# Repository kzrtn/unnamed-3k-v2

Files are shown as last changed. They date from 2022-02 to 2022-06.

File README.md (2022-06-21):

# unnamed-3k-v2 keypad
 A simple 3 key mechanical hotswap keypad for osu! Uses an Atmega32u2 (also compatible with Atmega16u2). Created using Kicad and AutoCad/Coreldraw.
 
 keypad image
 another keypad image
 
 ## IMPORTANT
 This uploaded version of the keypad is **slightly changed** from the prototype in the pictures above.
 
 **Changes:**
 - Removed in-key LEDs
 - Changed north facing switches to south facing
 - Switch pins were changed from B4, B6, B7 to B7, C7, C6
 - Removed unnecessary vias.

This means that what is put up here is **untested**. However if you've tried producing this and everything checks out (it should, changes were very minor) please send me an email at `jolene.tkk@gmail.com` or contact me somehow. I'll update this page and/or fix any issues raised.
 
 ## Features
 - Cherry MX hotswap
 - Uses QMK and has VIA (sort of)
 - 1000hz, chordsplits at 1ms
 - Acrylic sandwich
 - RGB underglow

**Notes regarding QMK and VIA:**

This is not pushed into QMK or VIA's repo. QMK source files are found in the firmware folder. To use VIA with the keypad, go to `settings tab in the VIA software > enable 'Show Design Tab > go to Design tab > Load Draft Definition > Upload the 'load_in_VIA.json' file from qmk-unnamed3kv2-source folder`. **You will have to do this each time you want to use VIA**.

## Settings and RGB modes
Upon plugging in, you will be booted into **Layer 0** where it outputs Z, X and C (play mode). To change RGB modes, hold down the first button (first button on the far left) while plugging in the keypad. It will boot into **Layer 1**.
### Layer 0
| First key  | Second key | Third key |
| --- | --- |--- |
| Z | X  | C |
### Layer 1
| First key  | Second key | Third key |
| --- | --- |--- |
| Change RGB Mode | Toggle RGB on/off | Go to Layer 2 |
### Layer 2
| First key  | Second key | Third key |
| --- | --- |--- |
| Hue value + | Hue value - | Go to Layer 3 |
### Layer 3
| First key  | Second key | Third key |
| --- | --- |--- |
| Sat value + | Sat value - | Go to Layer 4 |
### Layer 4
| First key  | Second key | Third key |
| --- | --- |--- |
| Brightness value + | Brightness value - | Go to Layer 0 |

**RGB MODES**

- Breathing
- Rainbow mood
- Rainbow swirl
- Static

## Required parts
- PCB with components
- Laser cut acrylic
- 4 x M2 17mm hex stands
- 8 x M2 screws
- (optional) Rubber feet

## PCB assembly tips
3D view PCB
PCB in Kicad

The BOM and POS files in `PCB files/Gerber and JLCPCB files` are generated for easy ordering from [JLCPCB](https://jlcpcb.com/). For any parts that are unavailable, especially the crystal and/or the capacitors for the crystal, choose something else that's also 16Mhz with another capacitive load value that's available. Calculate the new values for the caps of the new crystal accordingly using this formula:
```
CL = ((CX1 x CX2) / (CX1 + CX2)) + Cstray

CL: The crystal load capacitance
CX1: The first capacitor
CX2: The second capacitor
Cstray: The stray capacitance in the oscillator circuit, which will normally be in the 2pF to 5pF range.

Assuming that CX1=CX2 then the equation becomes:

CL = ((CX1 x CX1) / (2 x CX1)) + Cstray

CL = (CX1 / 2) + Cstray

Rearranging the equation, we can find the external load capacitor value:

CX1 = 2(CL - Cstray)

For example, if the crystal load capacitance is 15pF, and assuming Cstray=2pF, then:

CX1 = CX2 = 2(15pF - 2pF) = 26pF
```

In the event that you would like to use an **atmega16u2** instead of atmega32u2, you can just do that, no PCB edits is required. But please read the firmware notes section of this readme to adjust the firmware accordingly.

| Part name  | Package type | Notes |
| --- | --- |--- |
| Crystal  | SMD3225-4P  | 16MHz is REQUIRED |
| Capacitors  | 0805  |  |
| Resistors | 0805 | |
| Fuse | 1206 | [This](https://lcsc.com/product-detail/Resettable-Fuses_TECHFUSE-nSMD025-24V_C70069.html) is the one I used. Otherwise, ensure your fuse is rated 500mA |
| Kailh hotswap sockets |  | [They're](https://lcsc.com/product-detail/Mechanical-Keyboard-Shaft_Kailh-CPG151101S11_C2803348.html) now available on JLCPCB and LCSC |
| WS2812B (LEDs) |  | Easily found on [JLCPCB](https://lcsc.com/product-detail/Light-Emitting-Diodes-LED_Worldsemi-WS2812B-B-W_C2761795.html) and other websites |
| Tactile switch |  | Easily found on [JLCPCB](https://lcsc.com/product-detail/Tactile-Switches_ALPSALPINE-SKQGABE010_C115351.html) and other websites |

## Acrylic case notes
Case thickness

There are 3 different file formats here. AutoCAD, Coreldraw and PDF.

AutoCAD files are in the 'might be broken and wrong thickness' folder. When I tried exporting the AutoCAD files to .pdf, it would export in the wrong size. I'm not sure if the drawings themselves in the AutoCad files are wrong. They are also outdated, layers are not labelled with the correct thickness, if you use the AutoCAD files, please check the dimensions and the correct the thickness labels to the image shown above (image edited from `new laser cut 16.0.pdf`. The other issue with the AutoCAD file is that the USB cut out size is too big, it will not cover the underside of the USB port properly, if you plan to use AutoCAD, please edit this accordingly.

Coreldraw files are available in latest and 16.0 versions. I'm not sure if both of them are properly up to date (my Coreldraw trial has expired). Please check if they meet the requirements I pointed out in the paragraph above. I'd stick with the `new laser cut 16.0.pdf` file, because that's the last file I used.

**Additional note:** The holes for the hex stands can be quite tight in the `new laser cut 16.0.pdf` file. If they're too tight for your hex stands, enlarge them a little.

For best light diffusion effects, the last layer should use a matte/frosted piece of acrylic. The top of layer can also be matte/frosted for good light diffusion on the top.

## Firmware notes
To flash the firmware, use [QMK toolbox](https://github.com/qmk/qmk_toolbox). Load one of the `.hex` files provided in the `firmware/qmk hex files` folder. `unnamed3kv2_default.hex` does not have (manual) VIA support. `unnamed3kv2_via.hex` has (manual) VIA support. Make sure that the MCU is set to `atmega32u2`, if you are using `atmega16u2`, change it to that instead.

QMK toolbox

For tinkering with the firmware source, all the files are in `firmware/unnamed3kv2source`. To compile, use QMK MSYS.

**In the case where you are using an atmega16u2**, you'll have to edit the `rules.mk` file in `firmware/unnamed3kv2source`. Change `MCU = atmega32u2` to `MCU = atmega16u2` and recompile the firmware with [QMK MSYS](https://msys.qmk.fm/).

## Printing your own images for decoration
Reuse the same `new laser cut 16.0.pdf` file. Load it into an image editor like Photoshop and put it over whatever image you'd like to use and export it as an image or .pdf then print it out on a piece of paper. **Remember to check fill image to paper size** or similar setting your printer has. Make sure there is no margins so the printed image is the correct size.

**[Print settings example](https://cdn.discordapp.com/attachments/733003518465540278/988617787540930600/print_sizing.png)**

## Learning PCB design with this project
This makes a decent reference, but I don't advise using the same libraries as me because they're outdated and trigger clearance errors in Kicad. Please use [ebalster's keyboard parts library](https://github.com/ebastler/marbastlib) for parts instead.

**Useful resources**
- [My PCB design notes](https://docs.google.com/document/d/1xsjb1sf3pxFw8bXC4gNhWsFhWNOthMoyz6RiJc1UtVI/edit)
- [Best PCB design practices](https://gist.github.com/Sleepdealr/ab05f5edb82eae9e0393f4d63da55adf)

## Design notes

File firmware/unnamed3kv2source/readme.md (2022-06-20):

# unnamed-3k-v2

unnamed-3k-v2

*A short description of the keyboard/project*

* Keyboard Maintainer: [kzrtn](https://github.com/yourusername)
* Hardware Supported: *The PCBs, controllers supported*
* Hardware Availability: *Links to where you can find this hardware*

Make example for this keyboard (after setting up your build environment):

    make unnamed-3k-v2:default

Flashing example for this keyboard:

    make unnamed-3k-v2:default:flash

See the [build environment setup](https://docs.qmk.fm/#/getting_started_build_tools) and the [make instructions](https://docs.qmk.fm/#/getting_started_make_guide) for more information. Brand new to QMK? Start with our [Complete Newbs Guide](https://docs.qmk.fm/#/newbs).

## Bootloader

Enter the bootloader in 3 ways:

* **Bootmagic reset**: Hold down the key at (0,0) in the matrix (usually the top left key or Escape) and plug in the keyboard
* **Physical reset button**: Briefly press the button on the back of the PCB - some may have pads you must short instead
* **Keycode in layout**: Press the key mapped to `RESET` if it is available

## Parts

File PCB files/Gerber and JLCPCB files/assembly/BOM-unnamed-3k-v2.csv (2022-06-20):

Comment | Designator | Footprint | LCSC
MX-NoLED | MX2 | MXOnly-1U-Hotswap
MX-NoLED | MX3 | MXOnly-1U-Hotswap
MX-NoLED | MX1 | MXOnly-1U-Hotswap
1uF | C1 | C_0805_2012Metric_Pad1.15x1.40mm_HandSolder
10uF | C6 | C_0805_2012Metric_Pad1.15x1.40mm_HandSolder
0.1uF | C11 | C_0805_2012Metric_Pad1.15x1.40mm_HandSolder
10k | R3 | R_0805_2012Metric_Pad1.15x1.40mm_HandSolder
10k | R4 | R_0805_2012Metric_Pad1.15x1.40mm_HandSolder
5.1k | R5 | R_0805_2012Metric_Pad1.15x1.40mm_HandSolder
5.1k | R6 | R_0805_2012Metric_Pad1.15x1.40mm_HandSolder
PRTR5V0U2X | U2 | SOT143B
HRO-TYPE-C-31-M-12 | USB1 | HRO-TYPE-C-31-M-12-HandSoldering
ATmega32U2-AU | U1 | TQFP-32_7x7mm_P0.8mm
Polyfuse_Small | F1 | Fuse_1206_3216Metric_Pad1.42x1.75mm_HandSolder
SW_Push | SW1 | SKQGADE010
0.1uF | C5 | C_0805_2012Metric_Pad1.15x1.40mm_HandSolder
WS2812B | D5 | LED_WS2812B_PLCC4_5.0x5.0mm_P3.2mm
0.1uF | C10 | C_0805_2012Metric_Pad1.15x1.40mm_HandSolder
WS2812B | D4 | LED_WS2812B_PLCC4_5.0x5.0mm_P3.2mm
Crystal_GND24_Small | Y1 | Crystal_SMD_3225-4Pin_3.2x2.5mm_HandSoldering
14pF | C3 | C_0805_2012Metric_Pad1.15x1.40mm_HandSolder
14pF | C2 | C_0805_2012Metric_Pad1.15x1.40mm_HandSolder
0.1uF | C4 | C_0805_2012Metric_Pad1.15x1.40mm_HandSolder
22 | R2 | R_0805_2012Metric_Pad1.15x1.40mm_HandSolder
22 | R1 | R_0805_2012Metric_Pad1.15x1.40mm_HandSolder

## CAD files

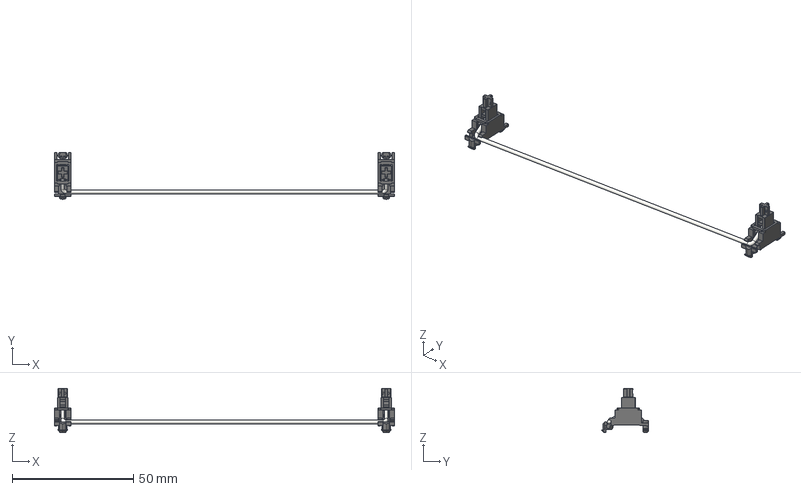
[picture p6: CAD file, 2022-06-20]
PCB files/keyswitch-kicad-library/source_3d/Mounting_Keyboard_Stabilizer/Stabilizer_Cherry_MX_8u.FCStd
140.1 x 19.2 x 18.3 mm
Bar
Stabilizer_Key_
Stabilizer_Base_
Stabilizer_Key
Stabilizer_Base

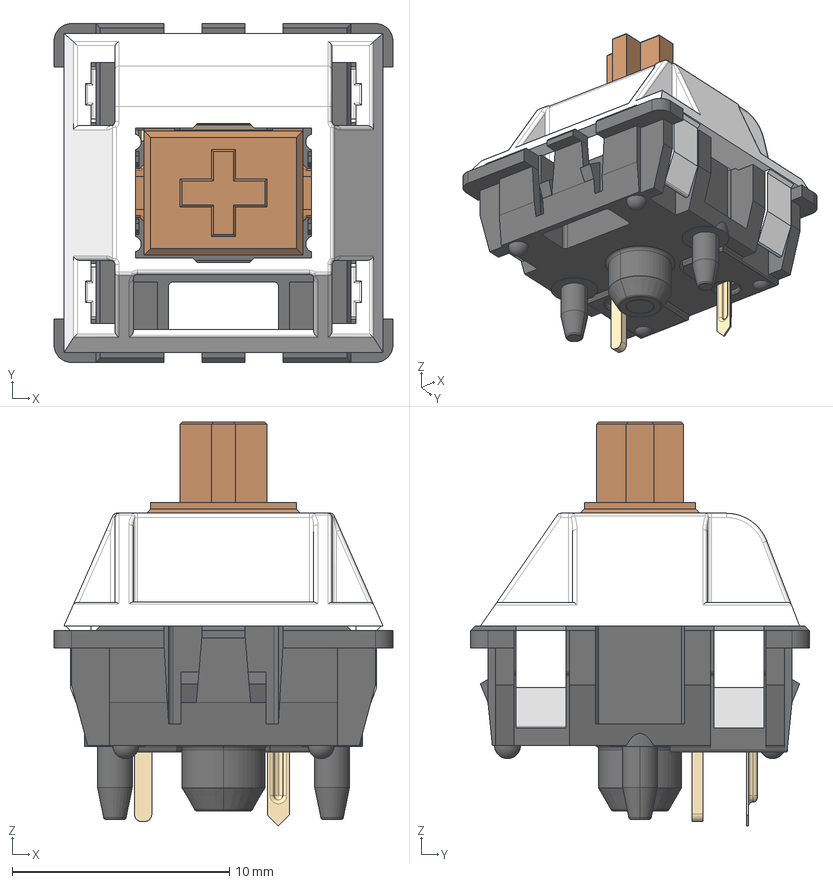
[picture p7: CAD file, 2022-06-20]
PCB files/keyswitch-kicad-library/source_3d/Switch_Keyboard_Cherry_MX/SW_Cherry_MX_PCB.FCStd
15.6 x 15.6 x 18.6 mm
Lower_Housing
Upper_Housing
Stem
Pin_1
Pin_2
Spring
Clicker

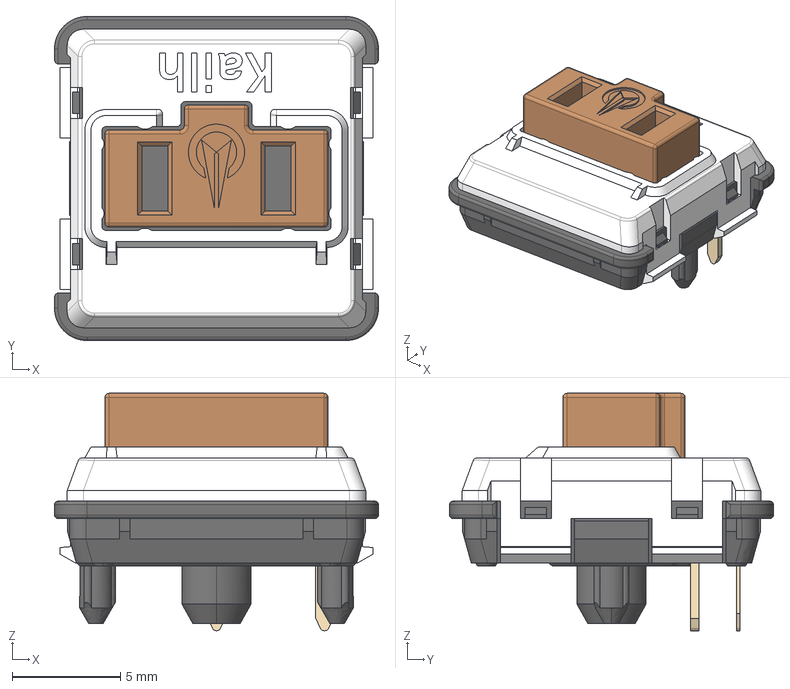
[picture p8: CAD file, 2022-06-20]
PCB files/keyswitch-kicad-library/source_3d/Switch_Keyboard_Kailh/SW_Kailh_Choc_V1.FCStd
15.0 x 15.0 x 11.0 mm
Upper_Housing
Lower_Housing
Stem
Pin_2
Pin_1

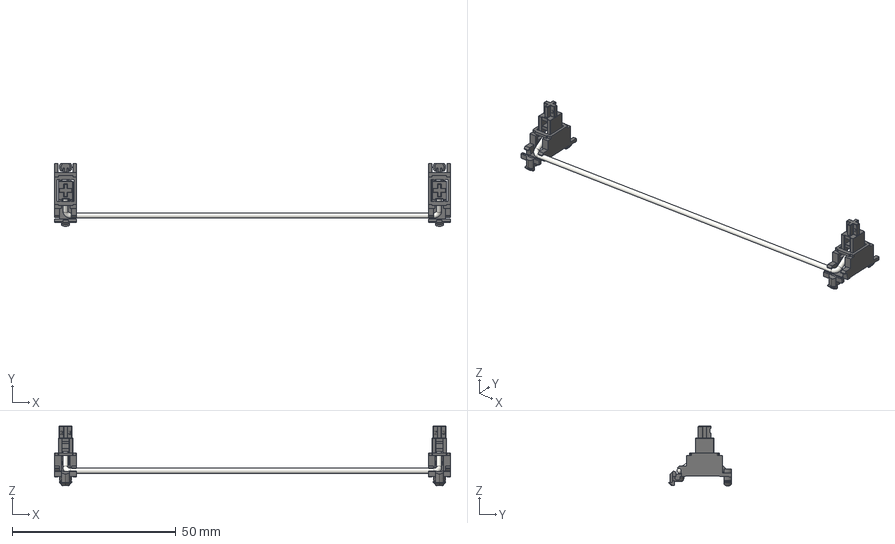
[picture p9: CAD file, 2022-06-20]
PCB files/keyswitch-kicad-library/source_3d/Mounting_Keyboard_Stabilizer/Stabilizer_Cherry_MX_7u.FCStd
121.1 x 19.2 x 18.3 mm
Bar
Stabilizer_Key_
Stabilizer_Base_
Stabilizer_Key
Stabilizer_Base

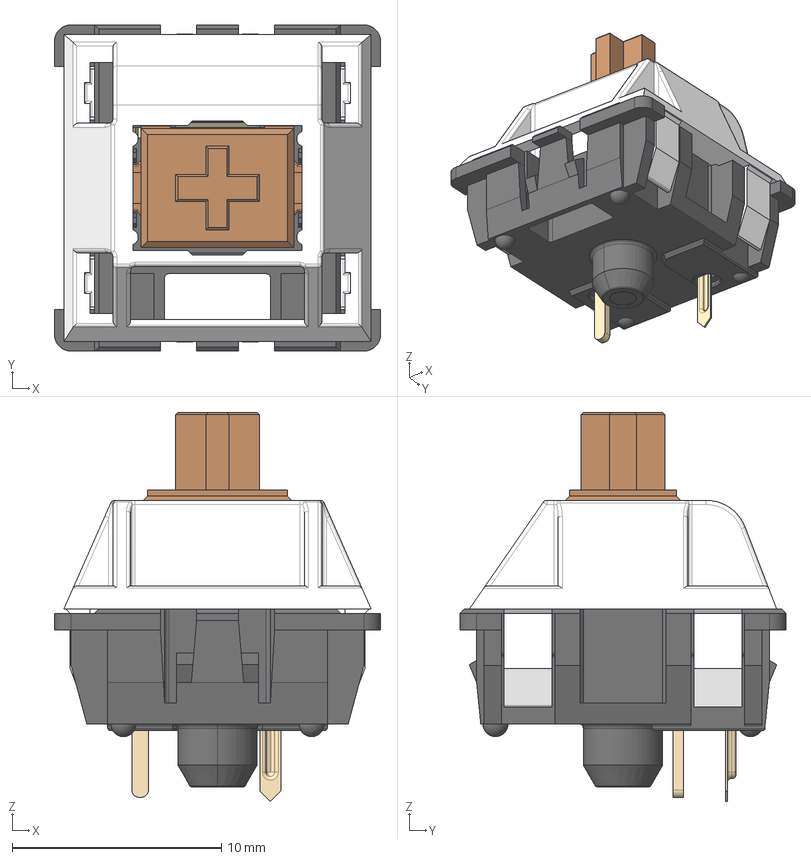
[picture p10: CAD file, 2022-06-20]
PCB files/keyswitch-kicad-library/source_3d/Switch_Keyboard_Cherry_MX/SW_Cherry_MX_Plate.FCStd
15.6 x 15.6 x 18.6 mm
Lower_Housing
Upper_Housing
Stem
Pin_1
Pin_2
Spring
Clicker

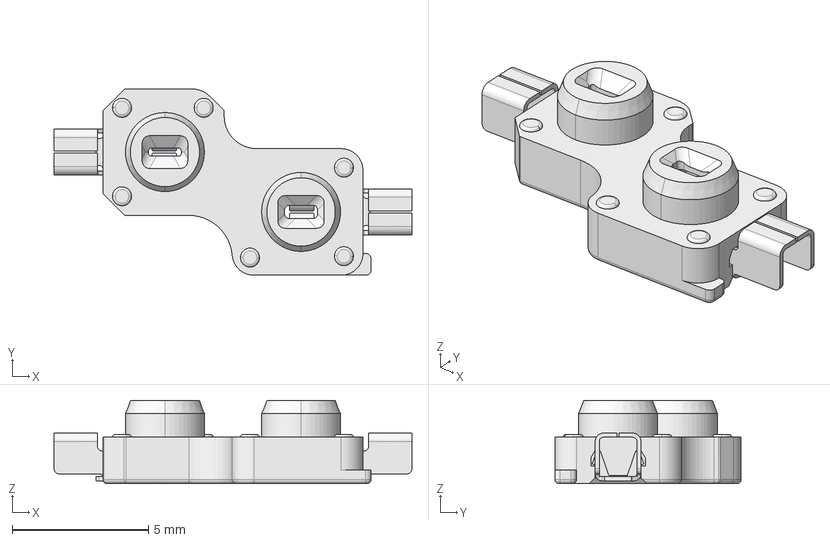
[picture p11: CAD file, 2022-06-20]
PCB files/keyswitch-kicad-library/source_3d/Switch_Keyboard_Kailh/SW_Hotswap_Kailh_Choc_v1.FCStd
13.2 x 6.85 x 3.05 mm

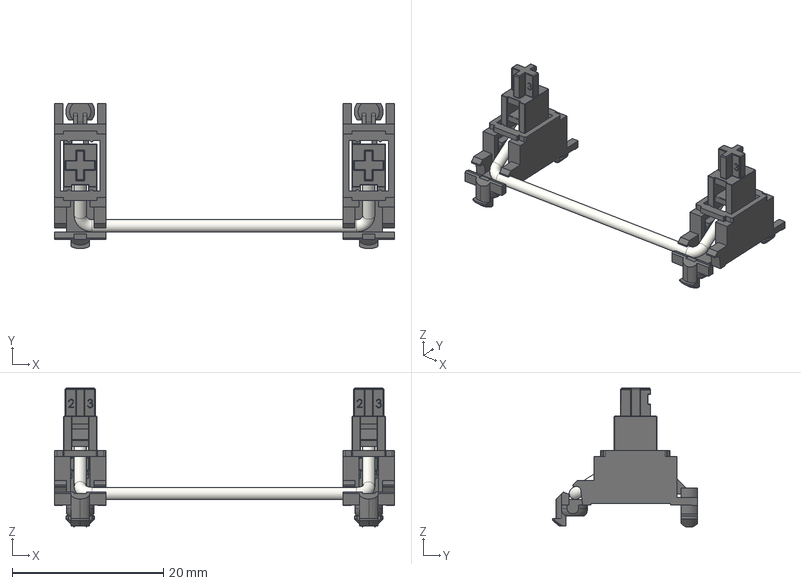
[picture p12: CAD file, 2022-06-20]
PCB files/keyswitch-kicad-library/source_3d/Mounting_Keyboard_Stabilizer/Stabilizer_Cherry_MX_3u.FCStd
44.9 x 19.2 x 18.3 mm
Bar
Stabilizer_Key_
Stabilizer_Base_
Stabilizer_Key
Stabilizer_Base

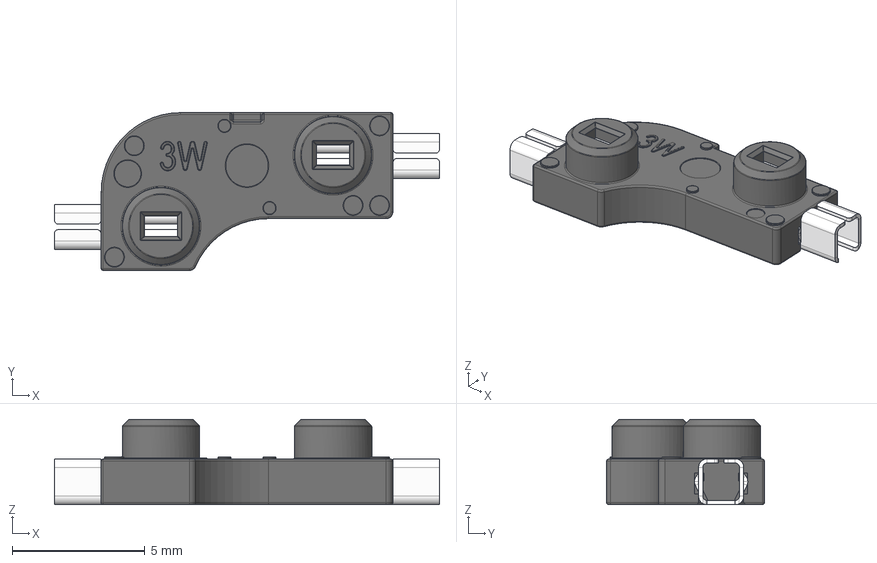
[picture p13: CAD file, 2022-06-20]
PCB files/keyswitch-kicad-library/source_3d/Switch_Keyboard_Kailh/SW_Hotswap_Kailh.FCStd
14.5 x 5.95 x 3.22 mm
Pin_1
Pin_2
Plastic

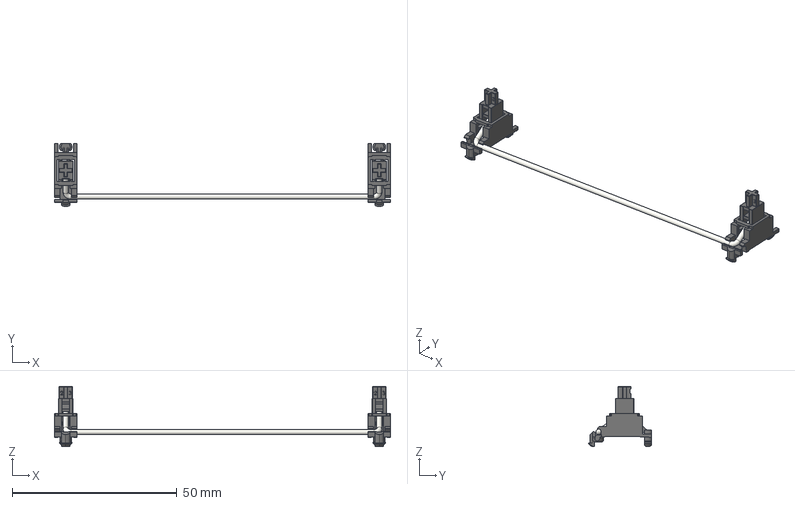
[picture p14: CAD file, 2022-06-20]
PCB files/keyswitch-kicad-library/source_3d/Mounting_Keyboard_Stabilizer/Stabilizer_Cherry_MX_6u.FCStd
102.1 x 19.2 x 18.3 mm
Bar
Stabilizer_Key_
Stabilizer_Base_
Stabilizer_Key
Stabilizer_Base

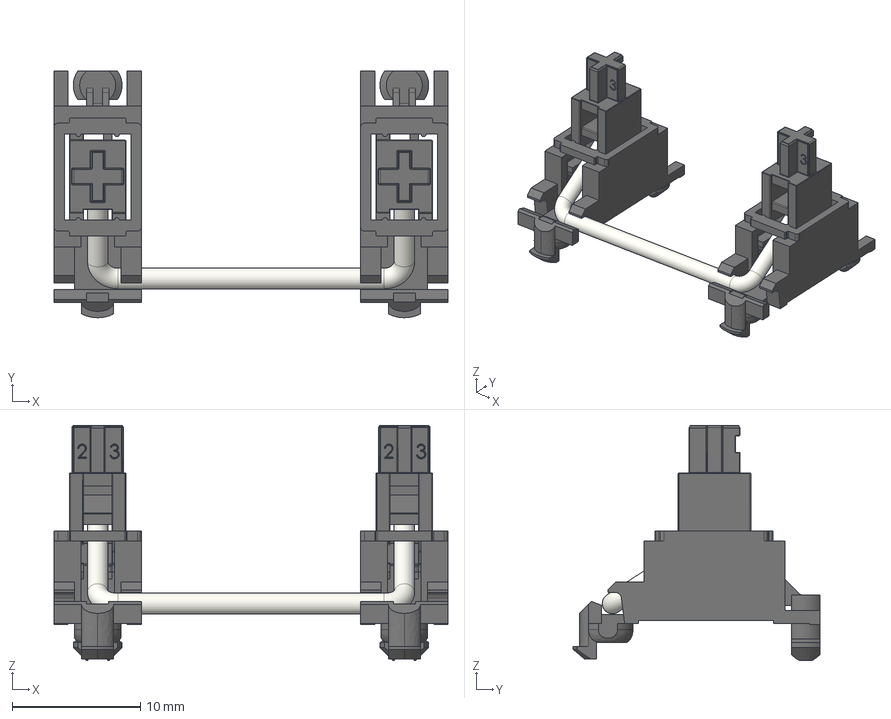
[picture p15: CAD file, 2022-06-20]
PCB files/keyswitch-kicad-library/source_3d/Mounting_Keyboard_Stabilizer/Stabilizer_Cherry_MX_2u.FCStd
30.7 x 19.2 x 18.3 mm
Bar
Stabilizer_Key_
Stabilizer_Base_
Stabilizer_Key
Stabilizer_Base

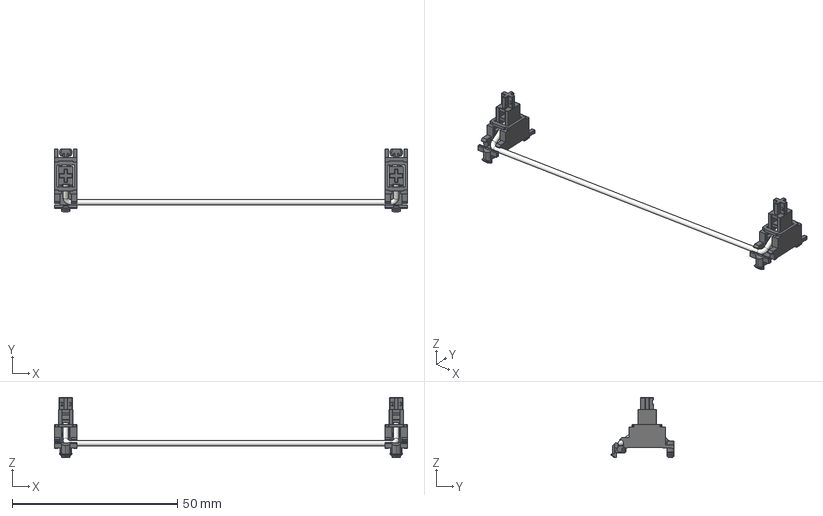
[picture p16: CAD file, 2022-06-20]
PCB files/keyswitch-kicad-library/source_3d/Mounting_Keyboard_Stabilizer/Stabilizer_Cherry_MX_6.25u.FCStd
106.8 x 19.2 x 18.3 mm
Bar
Stabilizer_Key_
Stabilizer_Base_
Stabilizer_Key
Stabilizer_Base

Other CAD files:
laser cutting files/might be broken and wrong thickness/Drawing1.dwg
laser cutting files/might be broken and wrong thickness/Drawing2.dwg

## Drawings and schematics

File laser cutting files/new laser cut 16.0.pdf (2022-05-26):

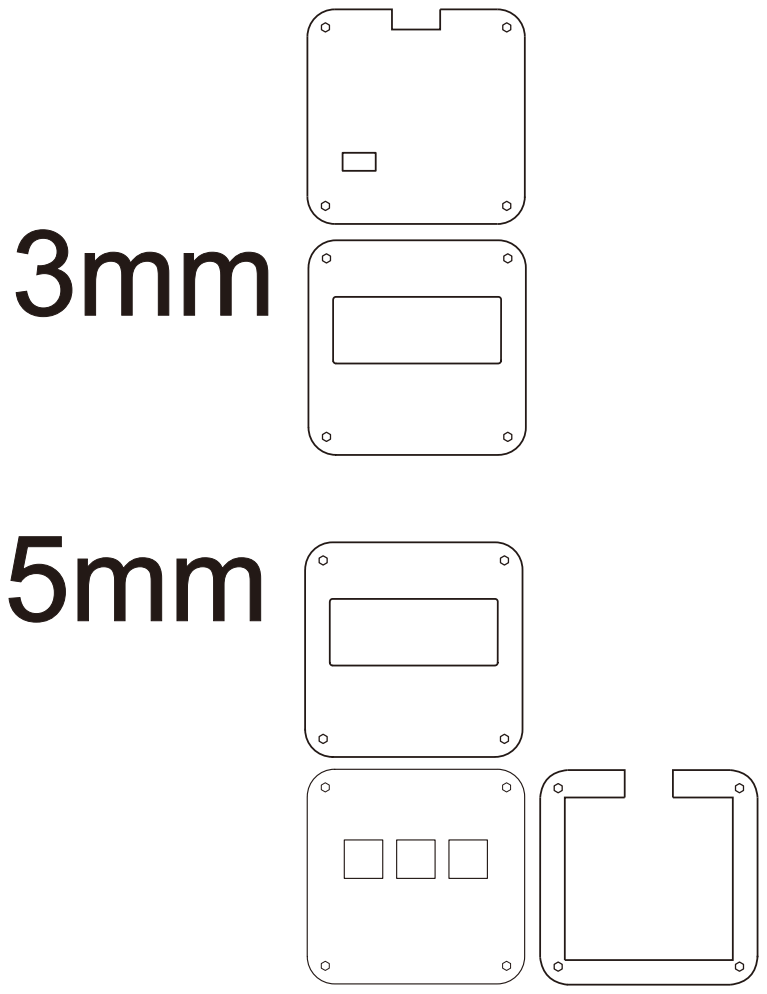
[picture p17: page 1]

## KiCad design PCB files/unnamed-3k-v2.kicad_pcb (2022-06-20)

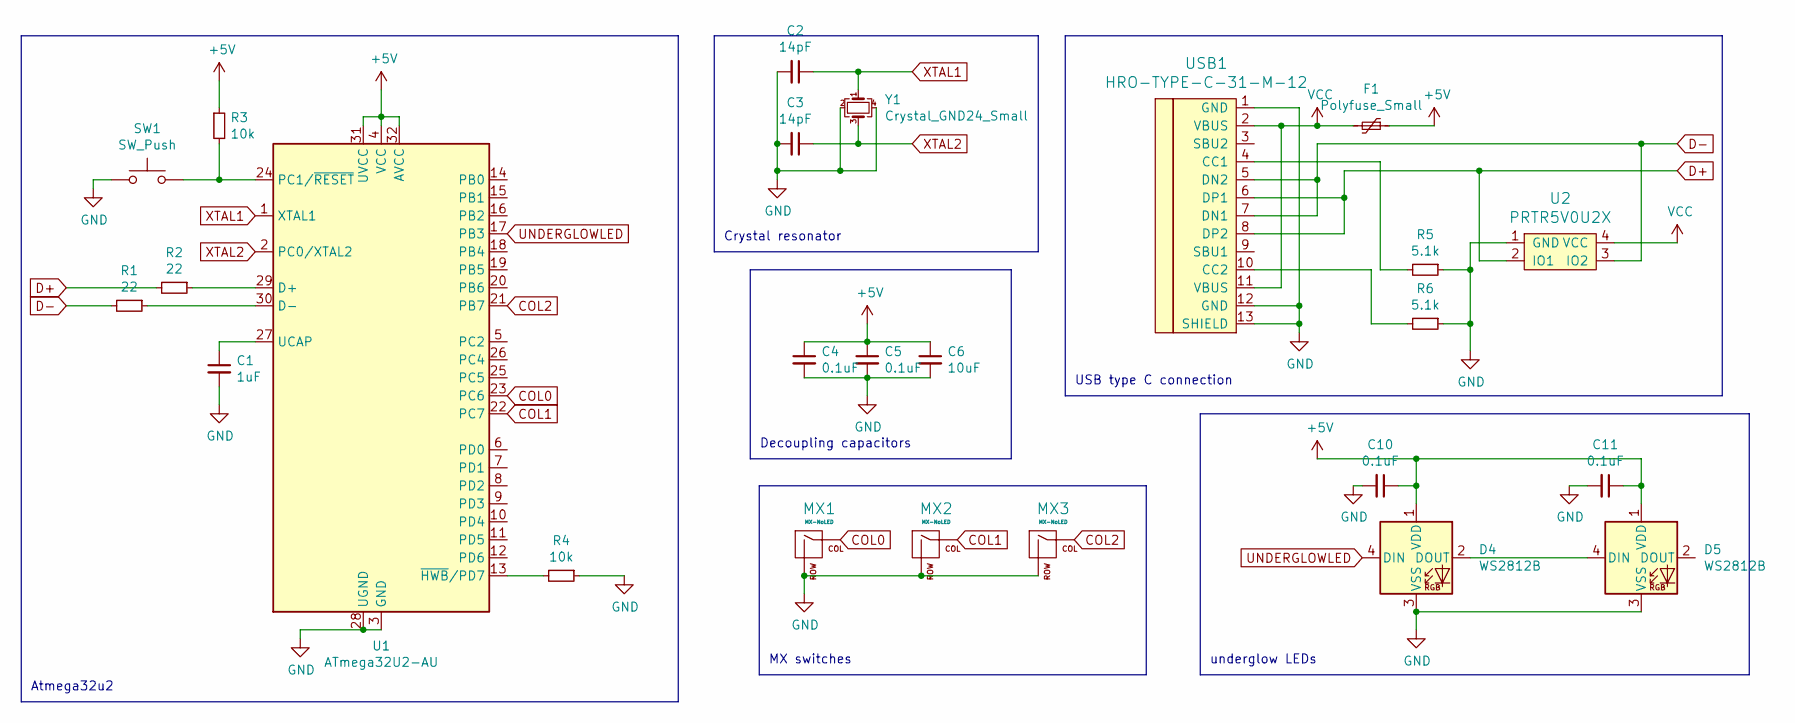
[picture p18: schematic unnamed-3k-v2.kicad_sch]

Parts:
C1: 1uF; C_0805_2012Metric_Pad1.15x1.40mm_HandSolder
C2, C3: 14pF; C_0805_2012Metric_Pad1.15x1.40mm_HandSolder
C4, C5, C10, C11: 0.1uF; C_0805_2012Metric_Pad1.15x1.40mm_HandSolder
C6: 10uF; C_0805_2012Metric_Pad1.15x1.40mm_HandSolder
D4, D5: WS2812B; LED_WS2812B_PLCC4_5.0x5.0mm_P3.2mm
F1: Polyfuse_Small; Fuse_1206_3216Metric_Pad1.42x1.75mm_HandSolder
MX1, MX2, MX3: MX-NoLED; MXOnly-1U-Hotswap
R1, R2: 22; R_0805_2012Metric_Pad1.15x1.40mm_HandSolder
R3, R4: 10k; R_0805_2012Metric_Pad1.15x1.40mm_HandSolder
R5, R6: 5.1k; R_0805_2012Metric_Pad1.15x1.40mm_HandSolder
SW1: SW_Push; SKQGADE010
U1: ATmega32U2-AU; TQFP-32_7x7mm_P0.8mm
U2: PRTR5V0U2X; SOT143B
USB1: HRO-TYPE-C-31-M-12; HRO-TYPE-C-31-M-12-HandSoldering
Y1: Crystal_GND24_Small; Crystal_SMD_3225-4Pin_3.2x2.5mm_HandSoldering

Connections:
+5V: C4.1, C5.1, C6.1, C10.1, C11.1, D4.1 (VDD), D5.1 (VDD), F1.1, R3.1, U1.4 (VCC), U1.31 (UVCC), U1.32 (AVCC)
COL0: MX1.1 (COL), U1.23 (PC6)
COL1: MX2.1 (COL), U1.22 (PC7)
COL2: MX3.1 (COL), U1.21 (PB7)
D+: R2.2, U2.2 (IO1), USB1.6 (DP1), USB1.8 (DP2)
D-: R1.2, U2.3 (IO2), USB1.5 (DN2), USB1.7 (DN1)
GND: C1.2, C2.2, C3.2, C4.2, C5.2, C6.2, C10.2, C11.2, D4.3 (VSS), D5.3 (VSS), MX1.2 (ROW), MX2.2 (ROW), MX3.2 (ROW), R4.1, R5.1, R6.1, SW1.1, U1.3 (GND), U1.28 (UGND), U2.1 (GND), USB1.1 (GND), USB1.12 (GND), USB1.13 (SHIELD), Y1.2, Y1.4
unnamed: C1.1, U1.27 (UCAP)
unnamed: D4.2 (DOUT), D5.4 (DIN)
unnamed: R1.1, U1.30 (D-)
unnamed: R2.1, U1.29 (D+)
unnamed: R3.2, SW1.2, U1.24 (PC1/~RESET)
unnamed: R4.2, U1.13 (~HWB/PD7)
unnamed: R5.2, USB1.4 (CC1)
unnamed: R6.2, USB1.10 (CC2)
UNDERGLOWLED: D4.4 (DIN), U1.17 (PB3)
VCC: F1.2, U2.4 (VCC), USB1.2 (VBUS), USB1.11 (VBUS)
XTAL1: C2.1, U1.1 (XTAL1), Y1.1
XTAL2: C3.1, U1.2 (PC0/XTAL2), Y1.3

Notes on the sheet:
Crystal resonator
Atmega32u2
USB type C connection
Decoupling capacitors
underglow LEDs
MX switches

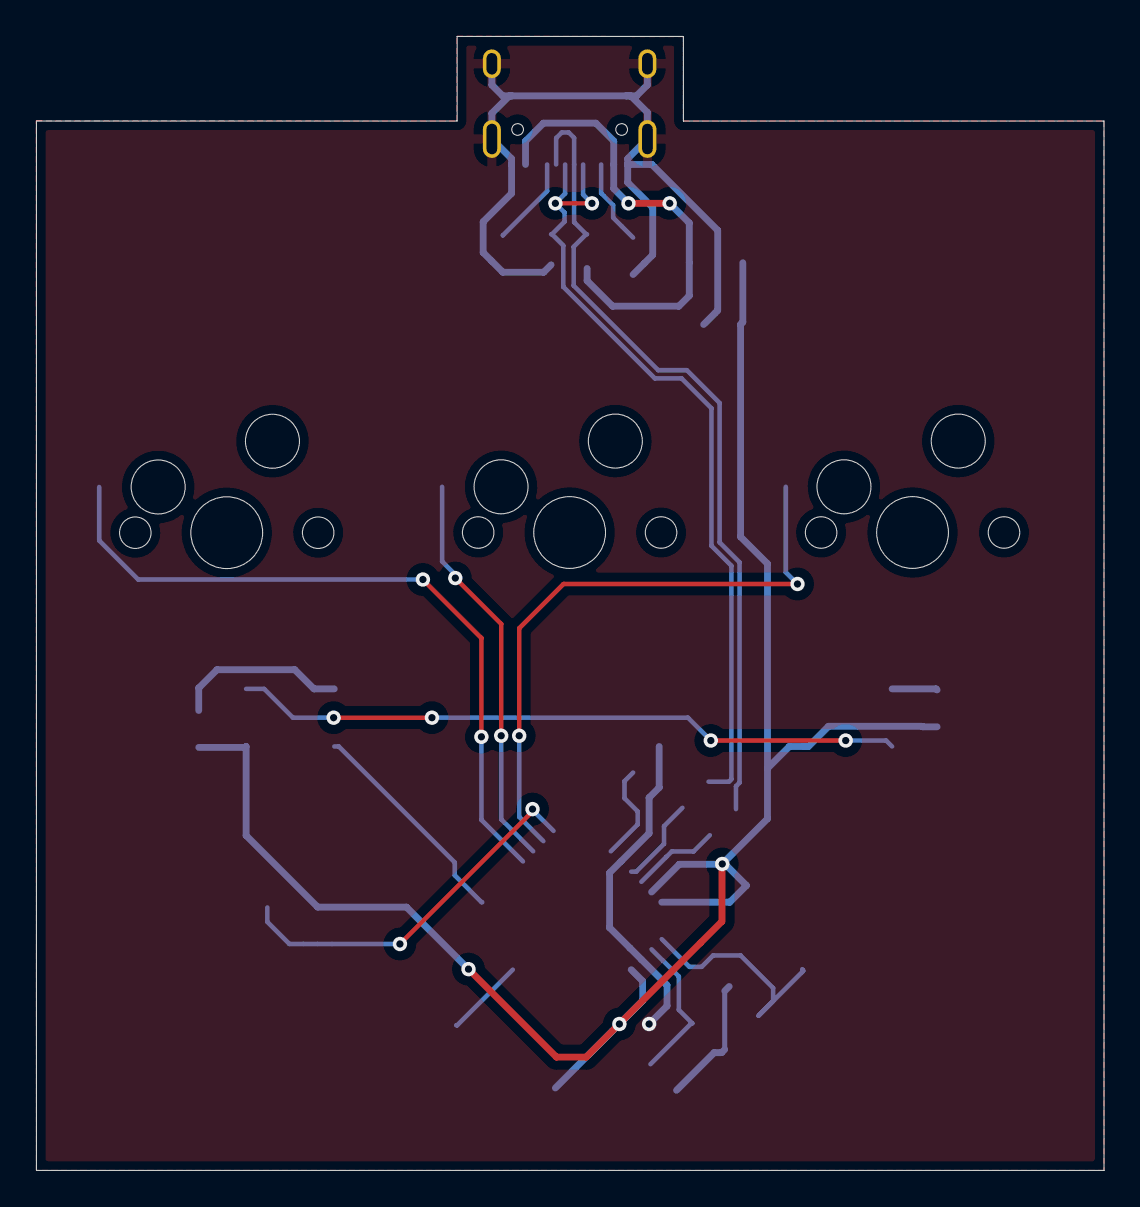
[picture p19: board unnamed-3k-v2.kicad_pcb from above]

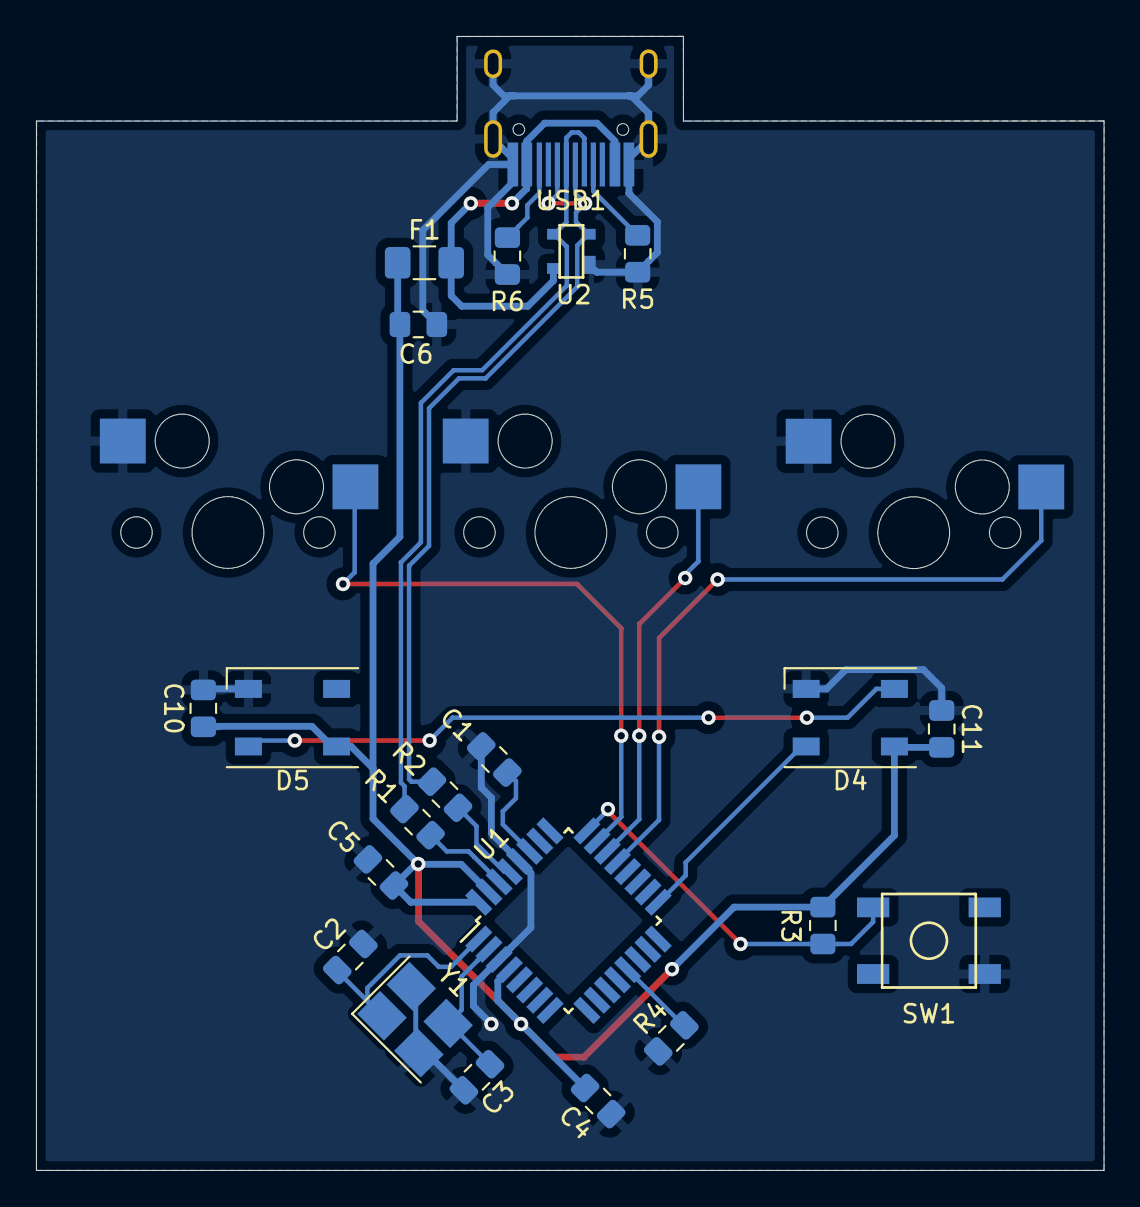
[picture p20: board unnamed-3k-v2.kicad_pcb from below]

Board: 2 copper layers, 59.3 x 63.0 mm, 25 parts (22 on the bottom side), 19 nets.

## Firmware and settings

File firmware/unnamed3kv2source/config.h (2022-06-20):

#pragma once

#include "config_common.h"

/* USB Device descriptor parameter */
#define VENDOR_ID    0x4B55
#define PRODUCT_ID   0x0000
#define DEVICE_VER   0x0001
#define MANUFACTURER kzrtn
#define PRODUCT      kzrtn unnamed3kv2

/* key matrix size */
#define MATRIX_ROWS 1
#define MATRIX_COLS 3

#ifndef DYNAMIC_KEYMAP_LAYER_COUNT
#define DYNAMIC_KEYMAP_LAYER_COUNT 5
#endif

#define BOOTMAGIC_LITE_ROW 0
#define BOOTMAGIC_LITE_COLUMN 0

/* direct pins */
#define DIRECT_PINS { \
    { B7, C7, C6} \
}

#define RGB_DI_PIN B3

#ifdef RGB_DI_PIN
  #define RGBLED_NUM 2
  #define RGBLIGHT_HUE_STEP 8
  #define RGBLIGHT_SAT_STEP 8
  #define RGBLIGHT_VAL_STEP 8
  #define RGBLIGHT_LIMIT_VAL 255
  #define RGBLIGHT_EFFECT_BREATHING
  #define RGBLIGHT_EFFECT_RAINBOW_MOOD
  #define RGBLIGHT_EFFECT_RAINBOW_SWIRL
  #define RGBLIGHT_DEFAULT_MODE RGBLIGHT_MODE_RAINBOW_MOOD
#endif

#define DEBOUNCE 3

#define USB_POLLING_INTERVAL_MS 1
#define QMK_KEYS_PER_SCAN 12
#define FORCE_NKRO

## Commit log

2022-01-29 Project Creation
    Created files
    [unnamed-3k-v2.kicad_pcb, unnamed-3k-v2.sch]
2022-01-29 Project Creation
    [unnamed-3k-v2.kicad_pcb, unnamed-3k-v2.sch]
2022-01-29 Added keyswitch kicad library
2022-01-30 PCB design and laser files finished
    [Drawing1.dwg, unnamed-3k-v2.sch]
2022-02-09 everything else
    [3mm clear layers.dxf, 3mm coloured layers.dxf, 3mm layers.dwg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]
2022-05-26 Final files
    [redone-3k-v2.kicad_pcb, unnamed-3k-v2.sch, unnamed-3k-v2_bom_.csv]
2022-06-20 Fixed PCB and firmware
    Removed in-key RGB and swapped south facing hotswap sockets to north facing
    [BOM-unnamed-3k-v2.csv, filled.kicad_pcb, redone-3k-v2.kicad_pcb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]
